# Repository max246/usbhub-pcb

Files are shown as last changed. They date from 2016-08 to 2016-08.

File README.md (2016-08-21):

# Opensource USB Hub PCB

I was looking to make a custom USB Hub for a project but I couldnt find any of them that worked and using the chip GL850G.
The chip is pretty old and cheap, but in my case I didnt need to use any of the fast transfering USB3, probably the next version can be based on this schematic.

I have took the schematic from a chinese website and re-written on eagle + designed the PCB, which is not the best compact and neat design but it worked as prototype.

I am offering all the files and part lists in case someone will want to make a custom USB Hub.

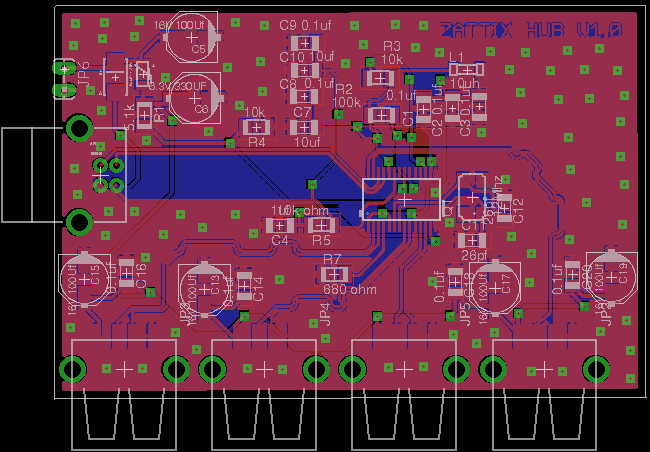
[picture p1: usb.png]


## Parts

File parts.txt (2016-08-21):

Partlist

Exported from usbhub.brd at 21/08/2016 19:15

EAGLE Version 7.5.0 Copyright (c) 1988-2015 CadSoft

Assembly variant: 

Part     Value          Package               Library               Position (mm)         Orientation

C1       0.1uf          C1206                 rcl                   (46.88 36.86)         R90
C2       0.1uf          C1206                 rcl                   (50.55 37.03)         R90
C3       0.1uf          C1206                 rcl                   (53.89 37.21)         R90
C4       1uf            C1206                 rcl                   (28.62 22.06)         R180
C5       16V 100Uf      PANASONIC_D           SparkFun-Passives     (17.43 46.03)         R180
C6       6.3V 330UF     PANASONIC_D           SparkFun-Passives     (17.81 38.32)         R180
C7       10uf           C1206                 rcl                   (31.72 34.59)         R0
C8       0.1uf          C1206                 rcl                   (31.68 38.49)         R0
C9       0.1uf          C1206                 rcl                   (31.84 45.3)          R0
C10      10uf           C1206                 rcl                   (31.79 41.82)         R0
C11      26pf           C1206                 rcl                   (53.01 20.22)         R0
C12      26pf           C1206                 rcl                   (57.12 24.31)         R270
C13      16V 100Uf      PANASONIC_D           SparkFun-Passives     (19.05 13.97)         R270
C14      0.1uf          C1206                 rcl                   (24.1 14.39)          R270
C15      16V 100Uf      PANASONIC_D           SparkFun-Passives     (3.81 15.24)          R270
C16      0.1uf          C1206                 rcl                   (9.16 16.07)          R270
C17      16V 100Uf      PANASONIC_D           SparkFun-Passives     (55.93 14.17)         R270
C18      0.1uf          C1206                 rcl                   (50.9 14.91)          R270
C19      16V 100Uf      PANASONIC_D           SparkFun-Passives     (70.74 15.47)         R270
C20      0.1uf          C1206                 rcl                   (65.81 15.85)         R270
D1       5v             SMA-DIODE_ALT         SparkFun-DiscreteSemi (7.78 40.98)          R90
F1       Fuse 1.1A 5V   PTC-1206              SparkFun-PowerIC      (11.24 41.31)         R270
JP1      USB-B          USB-B-PTH             SparkFun-Connectors   (5.85 28.49)          R0
JP2      USB-A-SMD      USB-A-S-NOSILK-FEMALE SparkFun-Connectors   (62.23 3.81)          R90
JP3      USB-A-SMD      USB-A-S-NOSILK-FEMALE SparkFun-Connectors   (8.89 3.81)           R90
JP4      USB-A-SMD      USB-A-S-NOSILK-FEMALE SparkFun-Connectors   (26.67 3.81)          R90
JP5      USB-A-SMD      USB-A-S-NOSILK-FEMALE SparkFun-Connectors   (44.45 3.81)          R90
JP6                     1X02_LOCK_LONGPADS    SparkFun-Connectors   (1.26 41.95)          R270
L1       10uh           SM-1206               inductor-neosid       (52.4 41.85)          R0
Q1       12Mhz          CTS406                crystal               (53.11 25.7)          R90
R1       5.1k           M1206                 rcl                   (11.46 36.12)         R270
R2       100k           M1206                 rcl                   (41.55 36.15)         R180
R3       10k            M1206                 rcl                   (41.34 40.84)         R0
R4       10k            M1206                 rcl                   (25.67 34.58)         R180
R5       10k ohm        M1206                 rcl                   (33.89 22.17)         R180
R7       680 ohm        M1206                 rcl                   (35.5 15.86)          R0
U$1      GL850G-31      TSSOP28               pimoroni              (44.45 25.4)          R90

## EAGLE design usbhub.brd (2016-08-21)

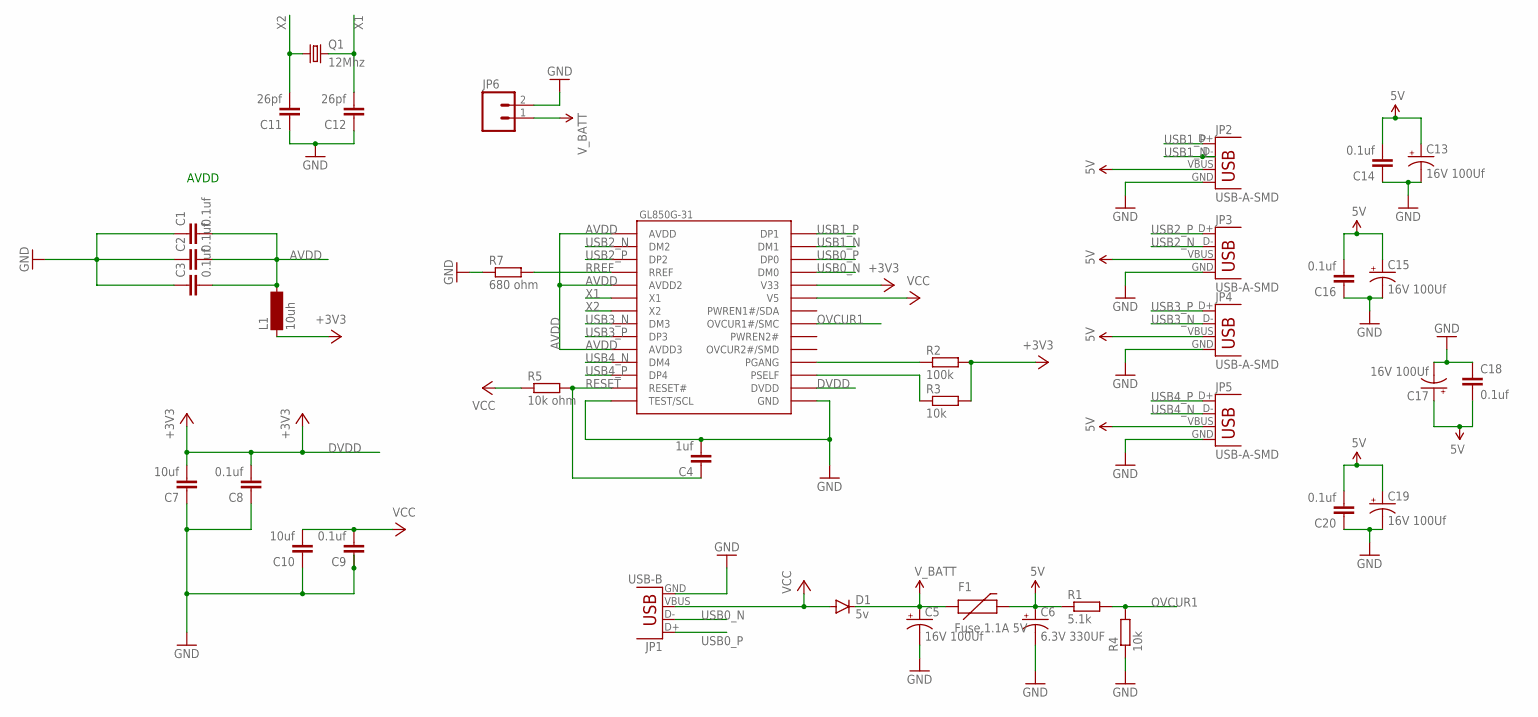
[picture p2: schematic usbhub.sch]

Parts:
C1, C2, C3, C8, C9, C14, C16, C18, C20: 0.1uf; C1206; MPN MCSH31B104K500CT
C4: 1uf; C1206; MPN 12061C105KAT2A
C5, C13, C15, C17, C19: 16V 100Uf; PANASONIC_D; MPN EEEHA1C101WP
C6: 6.3V 330UF; PANASONIC_D; MPN EEEHC0J331P
C7, C10: 10uf; C1206; MPN C1206C106K3PACTU
C11, C12: 26pf; C1206; MPN 12061A220JAT2A
D1: 5v; SMA-DIODE_ALT; MPN SMAJ5.0A
F1: Fuse 1.1A 5V; PTC-1206; MPN MICROSMD110F-2
JP1: USB-B; USB-B-PTH; MPN 292304-1
JP2, JP3, JP4, JP5: USB-A-SMD; USB-A-S-NOSILK-FEMALE
JP6: M02LOCK_LONGPADS; 1X02_LOCK_LONGPADS
L1: 10uh; SM-1206; MPN PFL3215-103MEB
Q1: 12Mhz; CTS406; MPN ABM3B-12.000MHZ-B2-T
R1: 5.1k; M1206; MPN CRCW12065K10FKEA.
R2: 100k; M1206; MPN WCR1206-100KFI
R3, R4: 10k; M1206; MPN MCMR12X1002FTL
R5: 10k ohm; M1206; MPN MCMR12X1002FTL
R7: 680 ohm; M1206; MPN WCR1206-680RFI
U$1: GL850G-31; TSSOP28

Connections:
5V: C6.+, C13.+, C14.2, C15.+, C16.2, C17.+, C18.2, C19.+, C20.2, F1.2, JP2.VBUS, JP3.VBUS, JP4.VBUS, JP5.VBUS, R1.1
+3V3: L1.1, R2.2, R3.2, U$1.24 (V33)
AVDD: C1.2, C2.2, C3.2, L1.2, U$1.1 (AVDD), U$1.5 (AVDD2), U$1.10 (AVDD3)
DVDD: C7.2, C8.2, U$1.16 (DVDD)
GND: C1.1, C2.1, C3.1, C4.2, C5.-, C6.-, C7.1, C8.1, C9.1, C10.1, C11.1, C12.1, C13.-, C14.1, C15.-, C16.1, C17.-, C18.1, C19.-, C20.1, JP1.GND, JP2.GND, JP3.GND, JP4.GND, JP5.GND, JP6.2, R4.1, R7.1, U$1.14 (TEST/SCL), U$1.15 (GND)
unnamed: R2.1, U$1.18 (PGANG)
unnamed: R3.1, U$1.17 (PSELF)
OVCUR1: R1.2, R4.2, U$1.21 (OVCUR1#/SMC)
RESET: C4.1, R5.2, U$1.13 (RESET#)
RREF: R7.2, U$1.4 (RREF)
USB0_N: JP1.D-, U$1.25 (DM0)
USB0_P: JP1.D+, U$1.26 (DP0)
USB1_N: JP2.D-, U$1.27 (DM1)
USB1_P: JP2.D+, U$1.28 (DP1)
USB2_N: JP3.D-, U$1.2 (DM2)
USB2_P: JP3.D+, U$1.3 (DP2)
USB3_N: JP4.D-, U$1.8 (DM3)
USB3_P: JP4.D+, U$1.9 (DP3)
USB4_N: JP5.D-, U$1.11 (DM4)
USB4_P: JP5.D+, U$1.12 (DP4)
VCC: C9.2, C10.2, D1.A, JP1.VBUS, R5.1, U$1.23 (V5)
V_BATT: C5.+, D1.C, F1.1, JP6.1
X1: C12.2, Q1.3 (2), U$1.6 (X1)
X2: C11.2, Q1.1, U$1.7 (X2)

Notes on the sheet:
AVDD

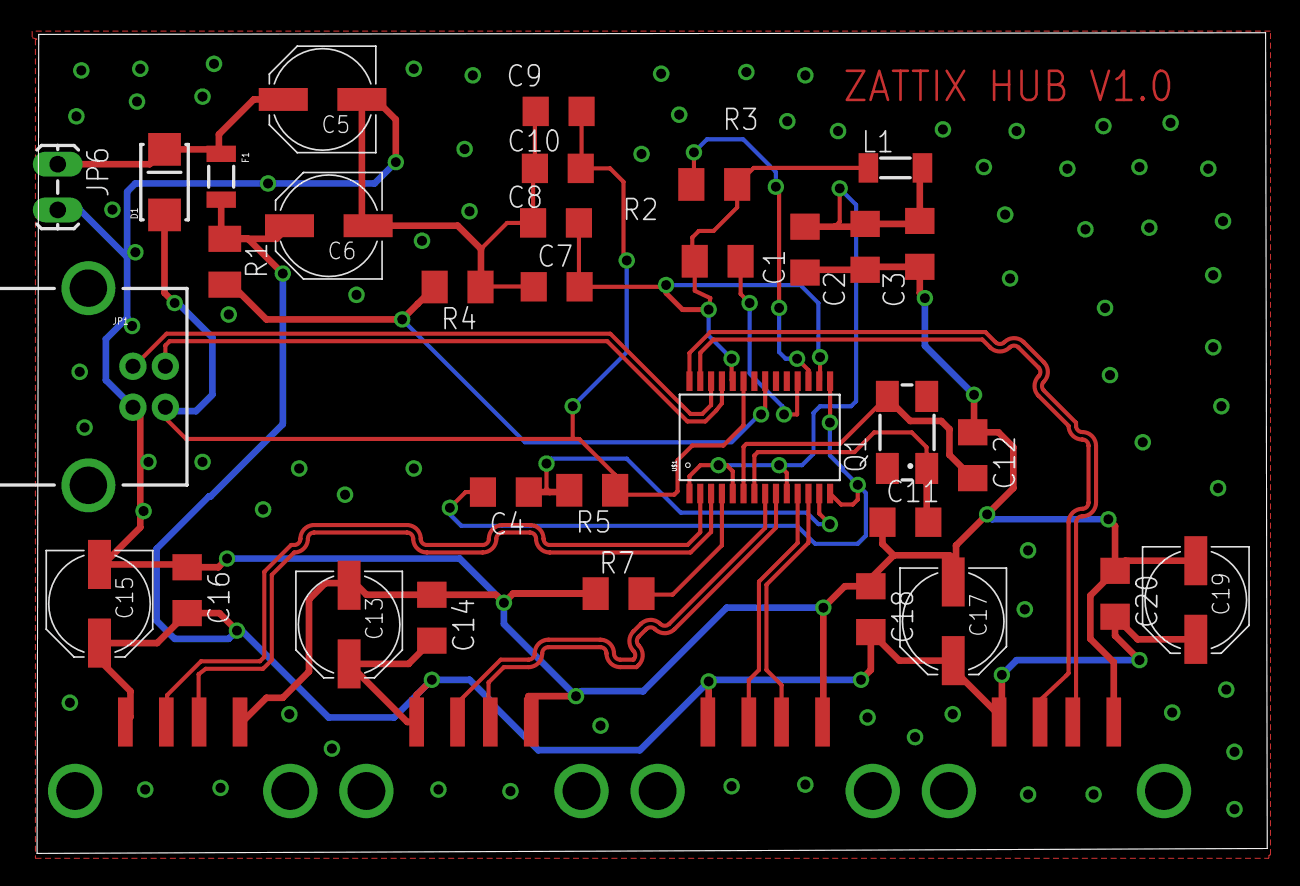
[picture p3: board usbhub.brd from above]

Board: 2 copper layers, 75.1 x 50.1 mm, 37 parts (0 on the bottom side), 24 nets.

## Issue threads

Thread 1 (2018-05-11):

Is this pcb is working properly?

R4wd0g, 2018-05-11:
Hello friend.
Did you ever mounted the PCB and tested?
I think this project pretty interesting.
May we use freely?
Thanks.

max246, 2018-05-13:
yes I did, but this chip was too hard to create, I made another one with another chip. you will see it on my repo.

Closed 2020-09-11.

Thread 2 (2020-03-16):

Long Lockpad?

AdriTeixeHax, 2020-03-16:
Hi, I've reached your project and seems really interesting to me. I'm currently learning a lot about electronics and I can't find any info about the Long Lockpads that you include in both the schematic and PCB layout. I'd want to know what's its purpose in the project or if it is even mandatory for the circuit. Thank you!

max246, 2020-03-18:
hey, do you have screenshot of what you are referring? I am not sure what is it :)

AdriTeixeHax, 2020-03-18:
Yes!
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

max246, 2020-03-19:
Oh I see, it wasnt label properly but this was the external power supply.
My usb hub was made to accept an external 5V when some hungry devices requiring more than what the normal USB can provide.

Dont need to use it, but just handy to have more juice :)

AdriTeixeHax, 2020-03-20:
Oh I see, thanks a lot!

Closed 2020-09-11.

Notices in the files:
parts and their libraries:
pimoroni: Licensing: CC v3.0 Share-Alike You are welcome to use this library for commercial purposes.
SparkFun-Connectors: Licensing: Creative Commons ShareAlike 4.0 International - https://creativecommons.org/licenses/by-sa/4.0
